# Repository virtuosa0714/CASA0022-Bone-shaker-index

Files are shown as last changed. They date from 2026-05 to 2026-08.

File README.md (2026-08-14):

# The Bone-Shaker Index 🚲💥

> **Mapping Road Surface Integrity & Comfort-Optimised Routing for Urban Micro-Mobility**
> 
> *A Master's Dissertation Project for MSc Connected Environments at UCL CASA.*






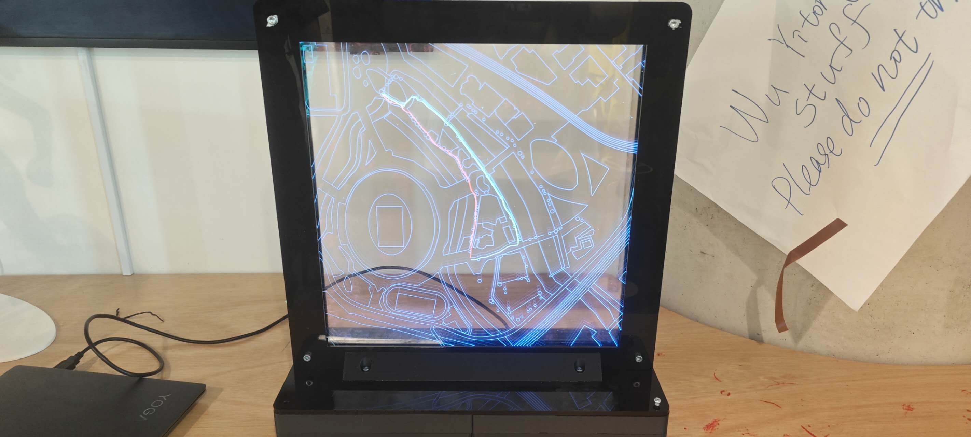
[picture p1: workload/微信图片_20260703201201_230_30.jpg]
Project Banner


## 📖 Overview

The promotion of active travel relies heavily on the quality and safety of cycling infrastructure. Traditional road surface monitoring methods are vehicle-centric, expensive, and fail to capture the high-frequency vibrations experienced by micro-mobility users. 

**The Bone-Shaker Index** is an open-source, low-cost Internet of Things (IoT) participatory sensing framework. It utilizes a bicycle-mounted edge-computing node to continuously monitor pavement conditions. By categorizing road anomalies and pushing this geospatial data to the cloud, the system empowers cyclists with a **Comfort-Weighted Pathfinding Algorithm** that prioritizes structural safety and ride smoothness over the shortest geographical distance.

## ✨ Key Features

*   **Edge-Processed Anomaly Detection:** Utilizes an ESP32-S3 and QMI8658 IMU to filter rider-induced kinematics (pedaling/steering) and accurately categorize infrastructural degradation (Moderate vs. Severe bumps) locally using a 1500ms debounce filter.
*   **Mobile Gateway Sync:** A Flutter-based mobile application that pairs with the hardware via BLE, appends precise GPS telemetry, and asynchronously syncs payloads to a NoSQL Firebase backend.
*   **Comfort-Weighted Dijkstra Routing:** A custom Leaflet.js web dashboard that mathematically penalizes degraded road nodes, actively routing cyclists around hazardous infrastructure.
*   **Tangible Data Visualisation:** A bespoke 3-tier, laser-cut physical exhibition model internally illuminated by LEDs, translating abstract JSON routing arrays into a compelling boundary object for urban advocacy.

---

## 🏗️ System Architecture

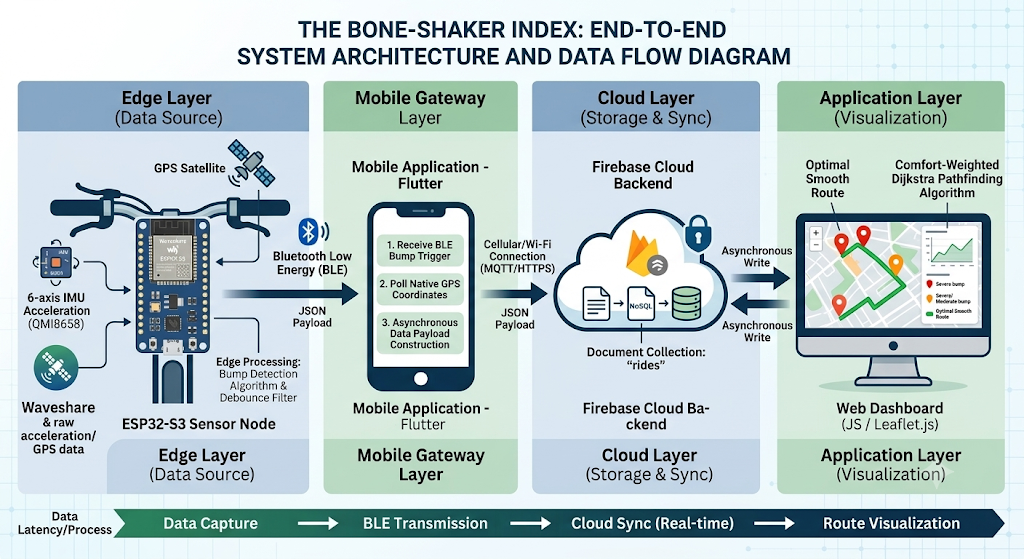
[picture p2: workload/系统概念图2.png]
System Architecture


The architecture operates sequentially across three primary nodes:
1.  **Edge Layer:** ESP32-S3 IMU sampling, gravity filtering, and BLE transmission.
2.  **Mobile Gateway:** Flutter app for GPS tagging and cellular cloud uplink.
3.  **Cloud & App Layer:** Firestore database synchronization and Leaflet.js rendering.

---

## 🛠️ Hardware Setup

The physical core is built around the **Waveshare ESP32-S3 Touch AMOLED 1.75**. To ensure the highest fidelity of inertial data, the sensor node is rigidly mounted to the bicycle's central main frame (top tube), effectively isolating steering noise.

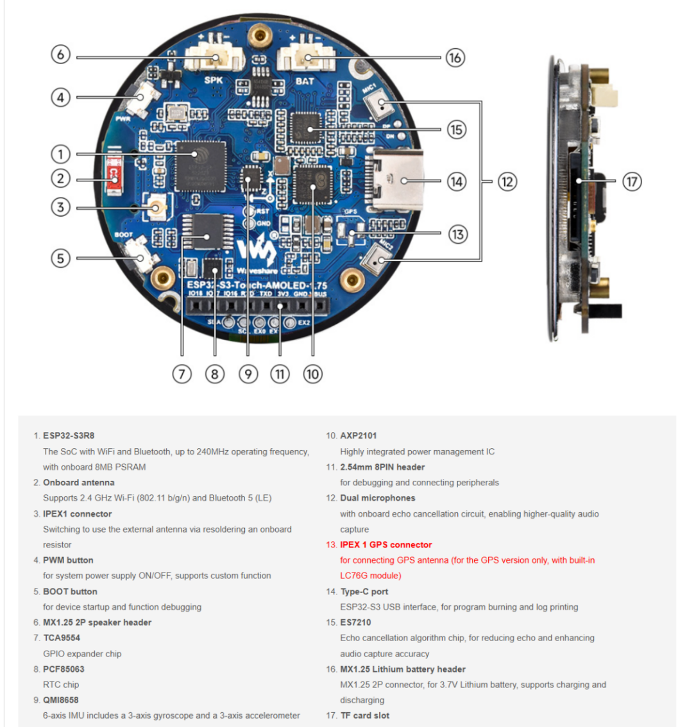
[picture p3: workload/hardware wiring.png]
Hardware Wiring and Mount


**Enclosure Design:**
A custom, weather-resistant enclosure was modeled in Autodesk Fusion and 3D printed. It enforces tight internal tolerances for the ESP32-S3 and Li-Po battery to minimize artificial high-frequency rattling. STL files are available in the `hardware_design/` folder.

---

## 💻 Software & Deployment

### 1. Edge Node Firmware (C++)
*   **Directory:** `/firmware`
*   **Setup:** Built with Arduino IDE / PlatformIO. Ensure the `ESP32` board manager is installed.
*   **Logic:** Samples Z-axis variance. `|ΔZ| >= 0.45G` (Moderate), `|ΔZ| >= 0.65G` (Severe).

### 2. Mobile Gateway (Flutter)
*   **Directory:** `/mobile_app`
*   **Setup:** Run `flutter pub get` to install BLE and Firebase dependencies.
*   **Function:** Background BLE scanning, GPS polling, and real-time UI feedback (Live Sync Active).

### 3. Web Dashboard (JavaScript / Leaflet.js)
*   **Directory:** `/web_dashboard`
*   **Setup:** A static web app. Configure your `firebaseConfig` object in `index.js`.
*   **Algorithm:** Implements coordinate-snapping (11m accuracy) and the custom Comfort-Weighted Dijkstra Algorithm.

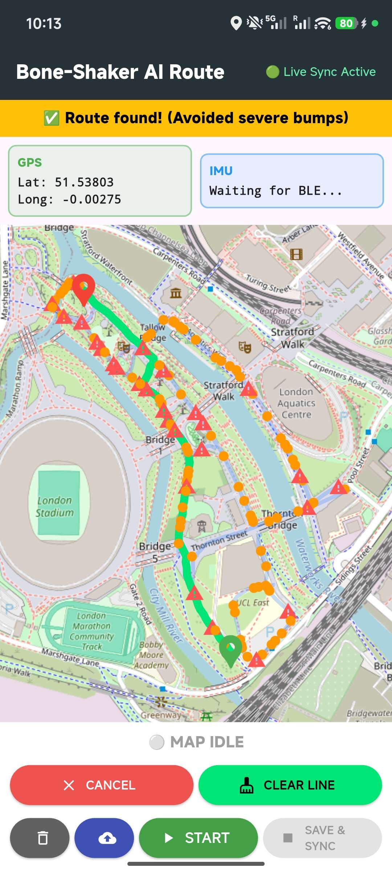
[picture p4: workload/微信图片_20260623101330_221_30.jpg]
App Dashboard
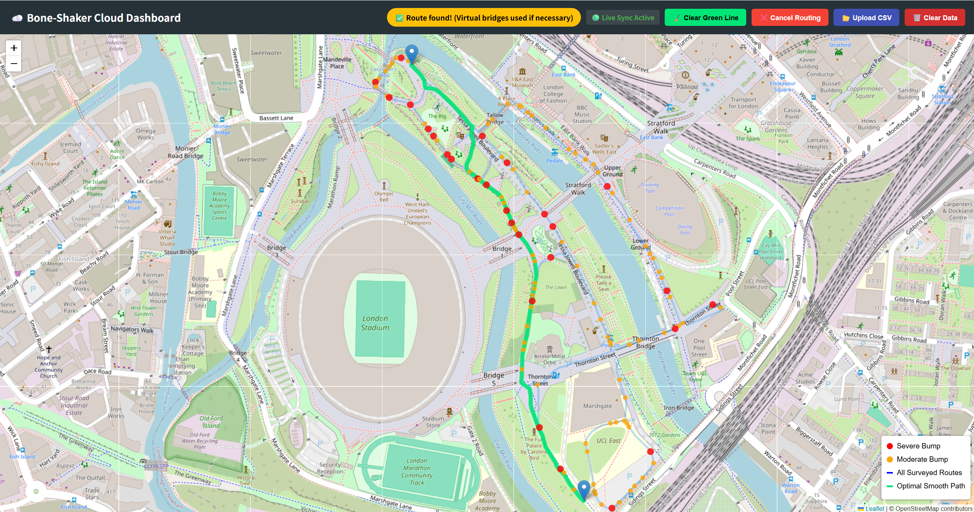
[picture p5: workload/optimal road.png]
Web Dashboard
 

---

## 📂 Repository Structure

```text
CASA0022-Bone-shaker-index/
│
├── firmware/                 # C++ source code for ESP32-S3 edge processing
├── mobile_app/               # Flutter mobile application (BLE Gateway & UI)
├── web_dashboard/            # Leaflet.js interactive map and routing engine
├── hardware_design/          # 3D STL files for enclosure & Laser-cut CAD files
├── data_analysis/            # Python scripts / Jupyter notebooks for CSV evaluation
├── docs/                     # Images, diagrams, and dissertation assets
└── README.md

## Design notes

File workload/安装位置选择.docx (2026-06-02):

通过直接的数据比对，结论非常明确：中间横梁（Main Frame）的效果远远好于前面把手（Handlebar）。

以下是基于你的真实测试数据得出的深度分析：

1. X轴（左右晃动）：把手位置的“转向噪音”极大

把手 (Handlebar) X轴波动标准差：0.216 g

横梁 (Main Frame) X轴波动标准差：0.087 g

分析：你可以从图表的第二栏（X-Axis）明显看到，蓝色线条（把手）的波动幅度远超红色线条（横梁），噪音是横梁的 2.5倍。这是因为在骑行过程中，为了保持平衡或避让，你的双手会不断微调方向盘。把手上的传感器把这些“人为的转向动作”全都记录成了加速度，这会严重干扰我们对“路面坑洼”的判断。横梁则非常稳定。

2. Y轴（前后加减速）：把手的姿态变化更多

把手 (Handlebar) Y轴波动标准差：0.165 g

横梁 (Main Frame) Y轴波动标准差：0.093 g

分析：图表第三栏（Y-Axis）显示，把手的纵向数据波动更大。当你捏刹车、身体前倾或摇车踩踏时，把手会发生位移或姿态倾斜。而车架中间横梁作为一个刚性整体，受骑行者姿势改变的干扰较小。

3. Z轴（上下颠簸）：横梁更能反映真实路况

最大瞬时冲击力 (Max Magnitude)：把手 2.19 g vs 横梁 1.96 g

分析：图表第一栏（Z-Axis）代表了我们最关心的上下颠簸（也是判定 The Bone-Shaker Index 的核心数据）。

把手的 Z 轴数据往往“失真”。一方面是因为前叉的形变或前避震器吸收了部分震动，另一方面由于双手压在把手上，人体手臂相当于“人肉避震”，导致短促而真实的地面冲击被放大或平滑掉了。

横梁的 Z 轴数据更加“纯粹”。横梁是自行车的承载骨架，它的 Z 轴加速度能更忠实地反映轮胎压过坑洼时车架受到的物理刚性冲击。

最终建议：选择“中间横梁”

既然装在后轮旁边容易引起干涉，那么装在中间横梁（上管或下管）就是你目前最佳的选择。

横梁位置的测试数据证明了：

它过滤掉了绝大部分由手部动作引起的 X 轴和 Y 轴假信号（噪音极低）。

它作为一个刚性结构，能够清晰、干净地记录下每一次颠簸（Z轴波动清晰）。

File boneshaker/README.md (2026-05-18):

# boneshaker

A new Flutter project.

## Getting Started

This project is a starting point for a Flutter application.

A few resources to get you started if this is your first Flutter project:

- [Learn Flutter](https://docs.flutter.dev/get-started/learn-flutter)
- [Write your first Flutter app](https://docs.flutter.dev/get-started/codelab)
- [Flutter learning resources](https://docs.flutter.dev/reference/learning-resources)

For help getting started with Flutter development, view the
[online documentation](https://docs.flutter.dev/), which offers tutorials,
samples, guidance on mobile development, and a full API reference.

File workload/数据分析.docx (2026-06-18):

数据核心特征提取

通过分析你的 Z 轴（垂直方向）数据，我们得出了以下基准指标：

静止基准线（重力加速度）：平均值为 -0.978 g。这意味着你的传感器 Z 轴是垂直向下的，平时受到的标准重力约为 1g。

常规骑行底噪：标准差（Std Dev）为 0.105 g。这是你平时骑行在普通路面上的轻微震动幅度。

最大颠簸冲击：记录到的最大绝对偏差达到了 0.932 g（瞬间读数接近 -1.91 g）。

判定标准设置建议

为了精准找出“坑洼”，你不能直接用原始的 Acc_Z 读数，而是应该先计算“动态垂直加速度（Dynamic Z）”，即剔除掉地球重力。

计算公式：动态 Z = 绝对值(Acc_Z - (-0.978))

(简算法：取 Acc_Z 绝对值后减去 0.98 即可)

基于你的实测数据（运用统计学的百分位数分布），我为你推荐以下 三级颠簸判定标准：

1. 正常粗糙路面（底噪过滤区）

阈值设置：动态 Z < 0.30 g

数据支撑：在你的测试中，95% 的时间里动态 Z 都小于 0.3g。这意味着只要冲击力低于这个值，都属于正常的柏油路颗粒震动或车架的正常轻微摇晃。程序可以直接忽略不记。

2. 中度颠簸（小坑洼/砖块路/井盖）

阈值设置：0.30 g ≤ 动态 Z < 0.45 g

数据支撑：覆盖了你数据中 95% ~ 99% 的少数波峰。

应用场景：这代表路面有明显的不平整（比如压过下沉的井盖或小裂缝）。如果你要在地图上画出“路况较差”的黄色轨迹，就筛选这个区间。

3. 严重坑洼 / 减速带 (Bone-Shaker 核心数据)

阈值设置：动态 Z ≥ 0.45 g

数据支撑：代表了你整趟骑行中最剧烈的前 1% 的物理冲击。你的最大冲击力达到了 0.93g。

应用场景：这是真正的“骨头粉碎者（Bone-Shaker）”。在地图上，这些点应该被标记为高危红色点位。当你的 App 检测到这个级别的数据时，就可以触发“坑洼记录”。

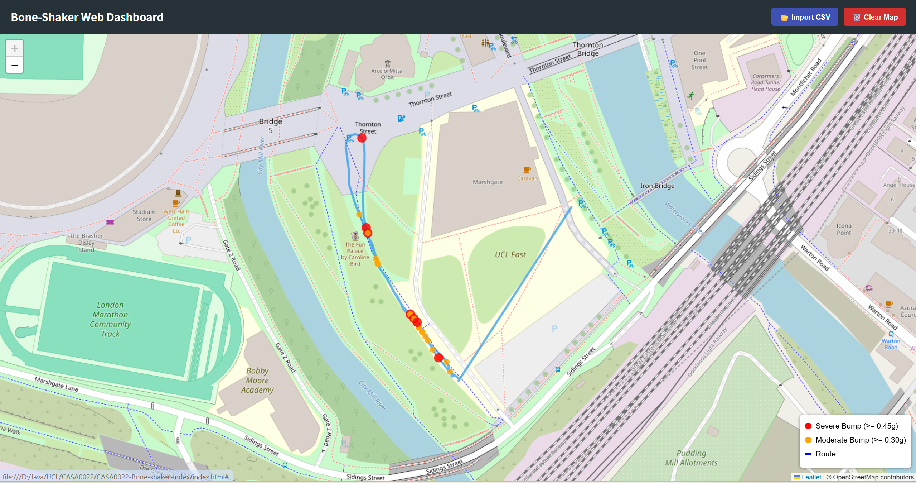
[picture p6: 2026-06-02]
workload/webmap.png

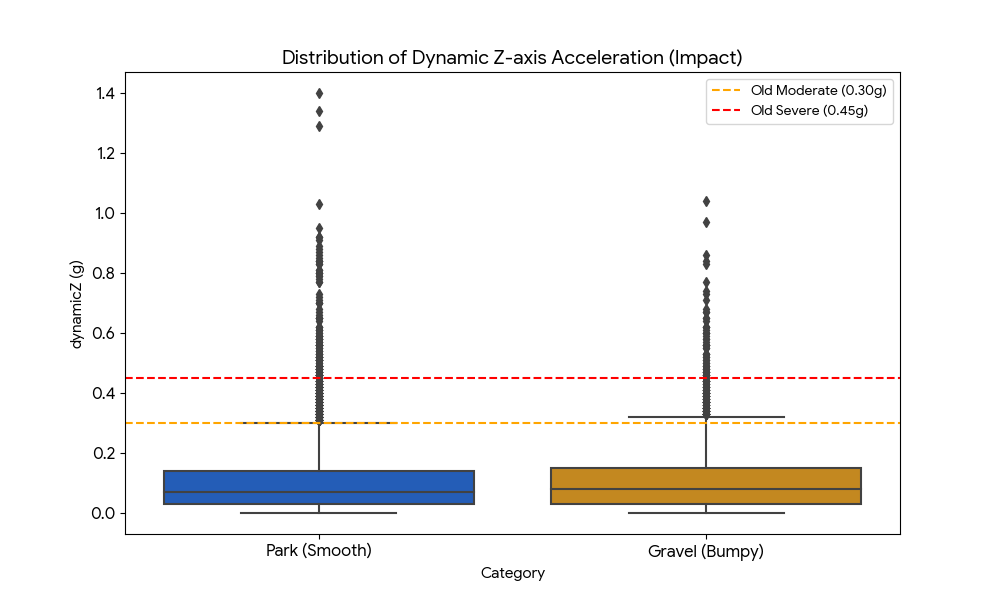
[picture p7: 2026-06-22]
workload/distribution.png

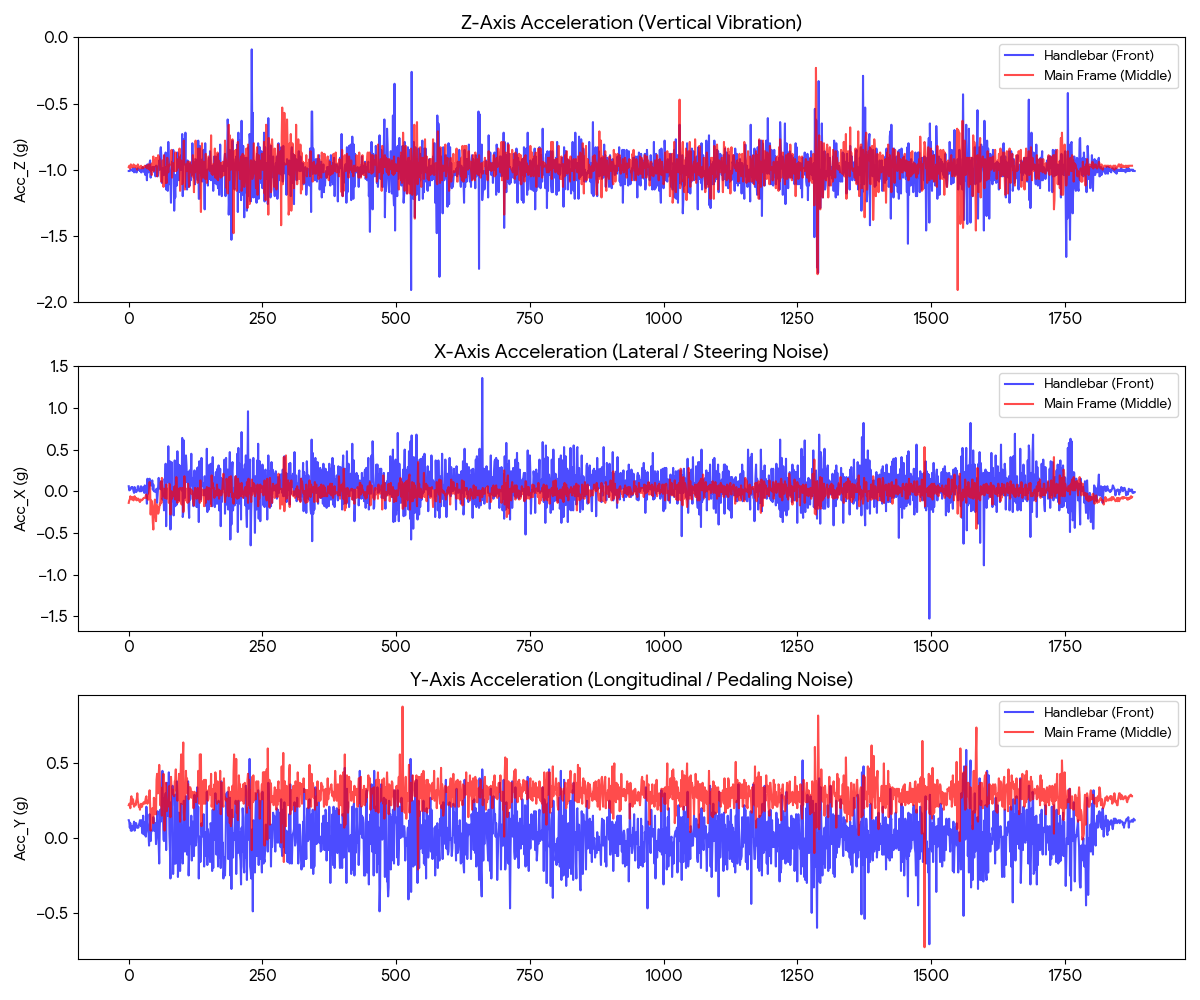
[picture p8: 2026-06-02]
workload/安装位置选择.png

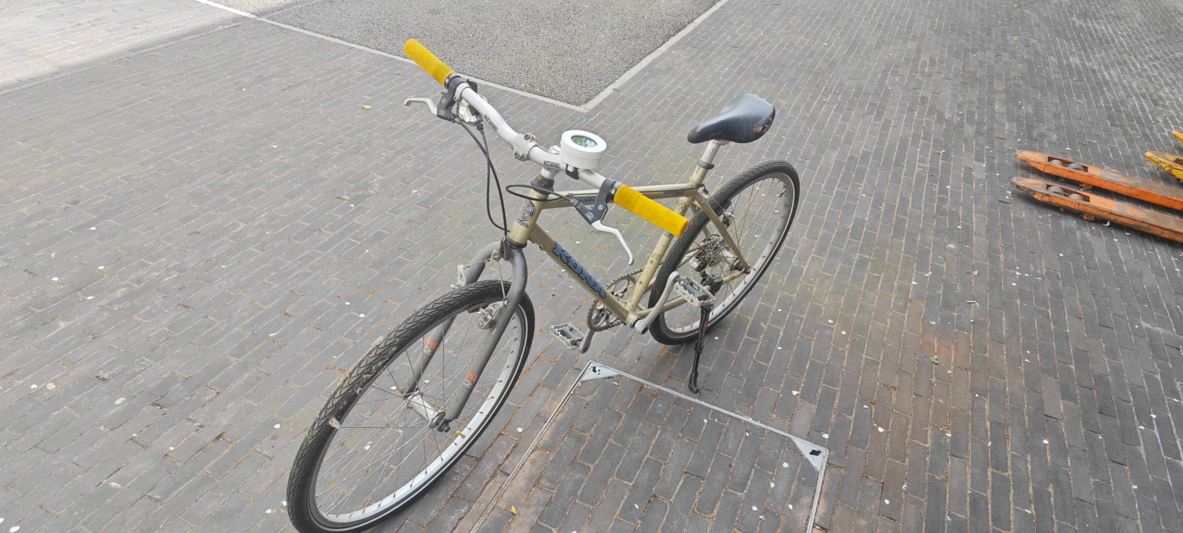
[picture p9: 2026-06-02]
workload/微信图片_20260601122134_171_30.jpg

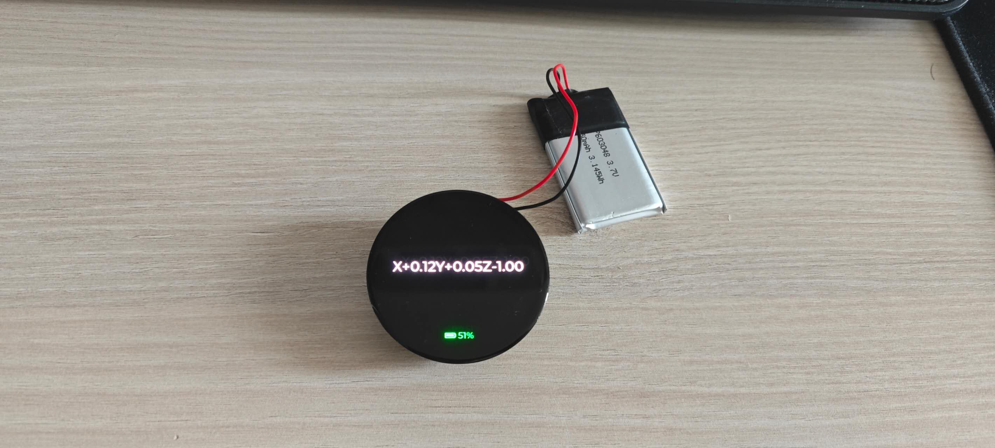
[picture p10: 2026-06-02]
workload/微信图片_20260518105642_153_30.jpg

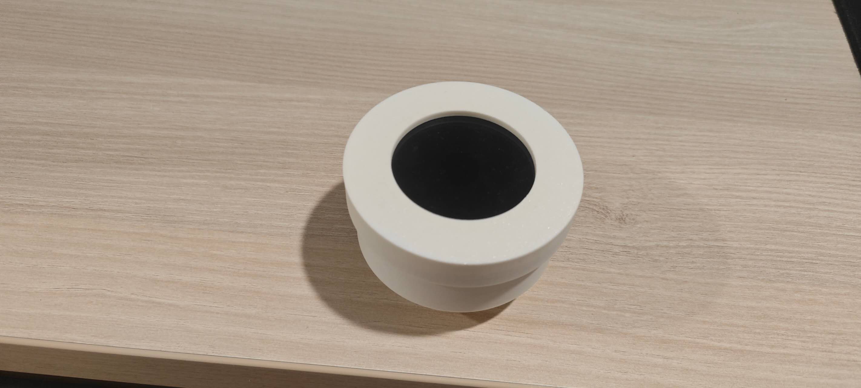
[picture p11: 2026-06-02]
workload/微信图片_20260530215353_166_30.jpg

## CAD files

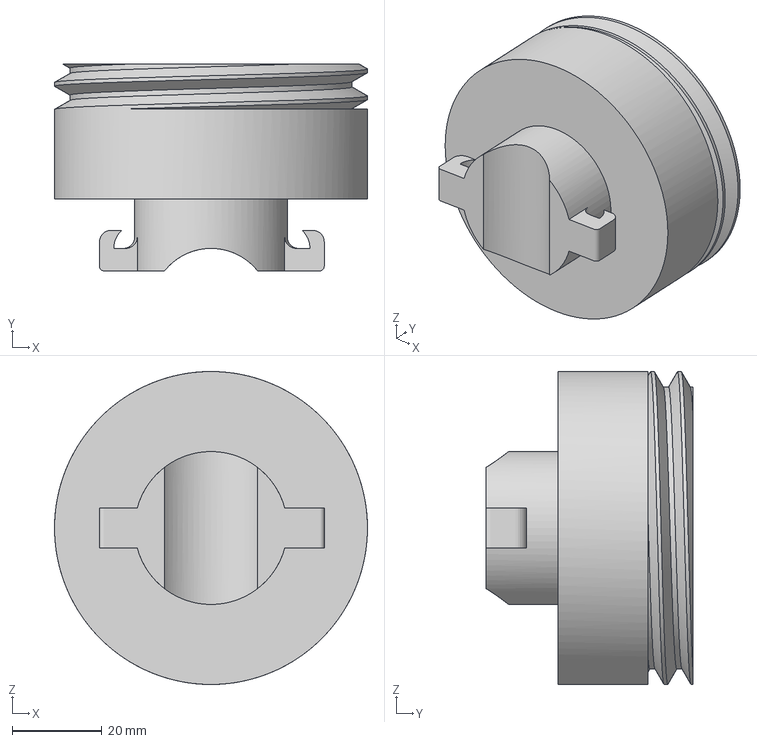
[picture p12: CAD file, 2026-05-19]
3Dprint/Body8.3mf
69.6 x 46.0 x 69.6 mm

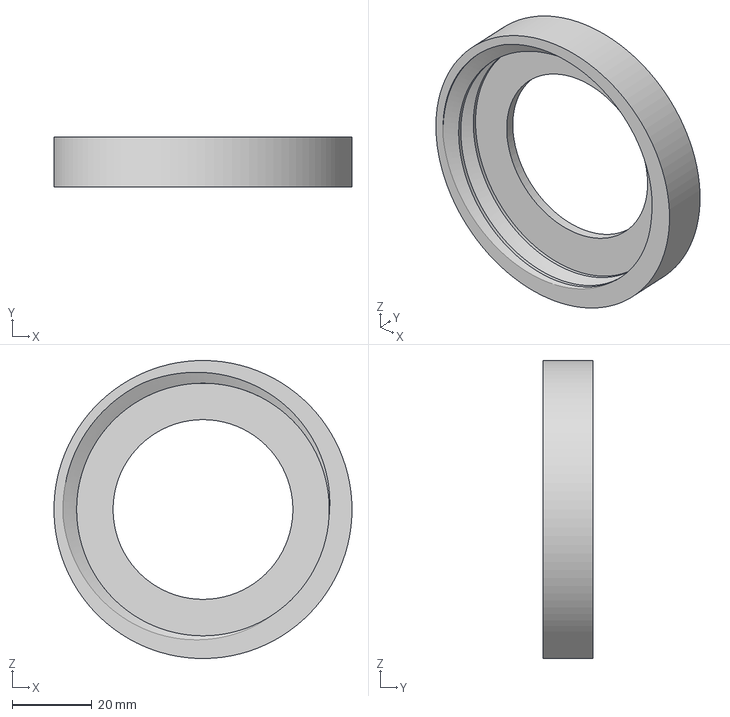
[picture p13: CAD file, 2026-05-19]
3Dprint/Body17.3mf
74.6 x 12.5 x 74.6 mm

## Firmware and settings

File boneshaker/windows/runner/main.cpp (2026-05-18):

#include <flutter/dart_project.h>
#include <flutter/flutter_view_controller.h>
#include <windows.h>

#include "flutter_window.h"
#include "utils.h"

int APIENTRY wWinMain(_In_ HINSTANCE instance, _In_opt_ HINSTANCE prev,
                      _In_ wchar_t *command_line, _In_ int show_command) {
  // Attach to console when present (e.g., 'flutter run') or create a
  // new console when running with a debugger.
  if (!::AttachConsole(ATTACH_PARENT_PROCESS) && ::IsDebuggerPresent()) {
    CreateAndAttachConsole();
  }

  // Initialize COM, so that it is available for use in the library and/or
  // plugins.
  ::CoInitializeEx(nullptr, COINIT_APARTMENTTHREADED);

  flutter::DartProject project(L"data");

  std::vector<std::string> command_line_arguments =
      GetCommandLineArguments();

  project.set_dart_entrypoint_arguments(std::move(command_line_arguments));

  FlutterWindow window(project);
  Win32Window::Point origin(10, 10);
  Win32Window::Size size(1280, 720);
  if (!window.Create(L"boneshaker", origin, size)) {
    return EXIT_FAILURE;
  }
  window.SetQuitOnClose(true);

  ::MSG msg;
  while (::GetMessage(&msg, nullptr, 0, 0)) {
    ::TranslateMessage(&msg);
    ::DispatchMessage(&msg);
  }

  ::CoUninitialize();
  return EXIT_SUCCESS;
}

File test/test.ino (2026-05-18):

#include <lvgl.h>
#include "Arduino_GFX_Library.h"
#include "pin_config.h"
#include "lv_conf.h"
#include <Arduino.h>
#include <Wire.h>
#include "SensorQMI8658.hpp"

// --- 电源管理库 ---
#include "XPowersLib.h" 

// --- 蓝牙相关头文件 ---
#include <BLEDevice.h>
#include <BLEServer.h>
#include <BLEUtils.h>
#include <BLE2902.h>

#define EXAMPLE_LVGL_TICK_PERIOD_MS 2

// --- 蓝牙配置 UUID ---
#define SERVICE_UUID           "6E400001-B5A3-F393-E0A9-E50E24DCCA9E"
#define CHARACTERISTIC_UUID_TX "6E400003-B5A3-F393-E0A9-E50E24DCCA9E"

BLEServer *pServer = NULL;
BLECharacteristic *pTxCharacteristic;
bool deviceConnected = false;

// 蓝牙连接状态回调
class MyServerCallbacks: public BLEServerCallbacks {
    void onConnect(BLEServer* pServer) {
      deviceConnected = true;
    };
    void onDisconnect(BLEServer* pServer) {
      deviceConnected = false;
      pServer->getAdvertising()->start();
    }
};

static lv_disp_draw_buf_t draw_buf;
static lv_color_t buf[LCD_WIDTH * LCD_HEIGHT / 10];
SensorQMI8658 qmi;
IMUdata acc;

// --- 电源管理与电量显示对象 ---
XPowersPMU power;
lv_obj_t *label_battery; 
lv_obj_t *label;

Arduino_DataBus *bus = new Arduino_ESP32QSPI(
  LCD_CS, LCD_SCLK, LCD_SDIO0, LCD_SDIO1, LCD_SDIO2, LCD_SDIO3);
Arduino_CO5300 *gfx = new Arduino_CO5300(
  bus, LCD_RESET, 0, LCD_WIDTH, LCD_HEIGHT, 6, 0, 0, 0);

void my_disp_flush(lv_disp_drv_t *disp, const lv_area_t *area, lv_color_t *color_p) {
  uint32_t w = (area->x2 - area->x1 + 1);
  uint32_t h = (area->y2 - area->y1 + 1);
#if (LV_COLOR_16_SWAP != 0)
  gfx->draw16bitBeRGBBitmap(area->x1, area->y1, (uint16_t *)&color_p->full, w, h);
#else
  gfx->draw16bitRGBBitmap(area->x1, area->y1, (uint16_t *)&color_p->full, w, h);
#endif
  lv_disp_flush_ready(disp);
}

void example_increase_lvgl_tick(void *arg) {
  lv_tick_inc(EXAMPLE_LVGL_TICK_PERIOD_MS);
}

void setup() {
  Serial.begin(115200);
  Wire.begin(IIC_SDA, IIC_SCL);

  // --- 电源管理芯片初始化 ---
  if(power.begin(Wire, AXP2101_SLAVE_ADDRESS, IIC_SDA, IIC_SCL)) {
    power.clearIrqStatus();
    power.enableBattVoltageMeasure();
    power.enableVbusVoltageMeasure(); 
  } else {
    Serial.println("PMU Init Failed!");
  }

  gfx->begin();
  gfx->setBrightness(200);

  // --- 蓝牙初始化 ---
  BLEDevice::init("ESP32_S3_IMU");
  pServer = BLEDevice::createServer();
  pServer->setCallbacks(new MyServerCallbacks());

  BLEService *pService = pServer->createService(SERVICE_UUID);
  pTxCharacteristic = pService->createCharacteristic(
                        CHARACTERISTIC_UUID_TX,
                        BLECharacteristic::PROPERTY_NOTIFY
                      );
  pTxCharacteristic->addDescriptor(new BLE2902());
  pService->start();
  pServer->getAdvertising()->start();
  Serial.println("BLE Ready!");

  // --- LVGL 初始化 ---
  lv_init();
  lv_disp_draw_buf_init(&draw_buf, buf, NULL, LCD_WIDTH * LCD_HEIGHT / 10);
  static lv_disp_drv_t disp_drv;
  lv_disp_drv_init(&disp_drv);
  disp_drv.hor_res = LCD_WIDTH;
  disp_drv.ver_res = LCD_HEIGHT;
  disp_drv.flush_cb = my_disp_flush;
  disp_drv.draw_buf = &draw_buf;
  lv_disp_drv_register(&disp_drv);

  const esp_timer_create_args_t lvgl_tick_timer_args = {
    .callback = &example_increase_lvgl_tick,
    .name = "lvgl_tick"
  };
  esp_timer_handle_t lvgl_tick_timer = NULL;
  esp_timer_create(&lvgl_tick_timer_args, &lvgl_tick_timer);
  esp_timer_start_periodic(lvgl_tick_timer, EXAMPLE_LVGL_TICK_PERIOD_MS * 1000);

  // ==========================================
  // 修改点：完全照搬 DeviceCode 的 UI 绘制逻辑
  // ==========================================
  // 1. 设置黑色背景
  lv_obj_set_style_bg_color(lv_scr_act(), lv_color_hex(0x000000), LV_PART_MAIN);

  // 2. 电池 UI 标签 (完全沿用你的参考代码样式)
  label_battery = lv_label_create(lv_scr_act());
  lv_obj_set_width(label_battery, 200); 
  lv_obj_set_style_text_color(label_battery, lv_color_hex(0x00FF00), LV_PART_MAIN);
  lv_obj_set_style_text_font(label_battery, &lv_font_montserrat_24, LV_PART_MAIN);
  lv_label_set_text(label_battery, LV_SYMBOL_BATTERY_FULL " --%");
  lv_obj_set_style_text_align(label_battery, LV_TEXT_ALIGN_CENTER, LV_PART_MAIN);
  lv_obj_align(label_battery, LV_ALIGN_BOTTOM_MID, 0, -40);

  // 3. 原有 IMU 数据标签 (改为白色，防止在黑色背景上隐身)
  label = lv_label_create(lv_scr_act());
  lv_obj_set_width(label, disp_drv.hor_res);
  lv_obj_set_style_text_color(label, lv_color_hex(0xFFFFFF), LV_PART_MAIN);
  lv_obj_set_style_text_align(label, LV_TEXT_ALIGN_CENTER, 0);
  lv_obj_set_style_text_font(label, &lv_font_montserrat_40, 0);
  lv_obj_set_style_text_line_space(label, 10, 0);
  lv_obj_align(label, LV_ALIGN_CENTER, 0, -20); // 稍微往上移一点，不要挡住电量
  lv_label_set_text(label, "Initializing...");

  if (!qmi.begin(Wire, QMI8658_L_SLAVE_ADDRESS, IIC_SDA, IIC_SCL)) {
    lv_label_set_text(label, "Sensor Error!");
    while (1) { delay(1000); }
  }

  qmi.configAccelerometer(SensorQMI8658::ACC_RANGE_4G, SensorQMI8658::ACC_ODR_1000Hz, SensorQMI8658::LPF_MODE_0);
  qmi.enableAccelerometer();
}

void loop() {
  lv_timer_handler();

  // 定期刷新电池状态（这里保留了 2 秒读取一次的优化，防止 I2C 堵塞导致你主程序的 IMU 掉帧）
  static unsigned long lastBatteryUpdate = 0;
  if (millis() - lastBatteryUpdate > 2000) {
    lastBatteryUpdate = millis();
    char bat_buf[32];
    const char* pwr_icon = LV_SYMBOL_BATTERY_FULL;
    
    // 以下判断逻辑与 DeviceCode.ino 完全一致
    if (power.isVbusIn()) {
      pwr_icon = power.isCharging() ? LV_SYMBOL_CHARGE : LV_SYMBOL_USB;
    }

    if (power.isBatteryConnect()) {
      snprintf(bat_buf, sizeof(bat_buf), "%s %d%%", pwr_icon, power.getBatteryPercent());
    } else {
      snprintf(bat_buf, sizeof(bat_buf), "%s NO BAT", pwr_icon);
    }
    lv_label_set_text(label_battery, bat_buf);
  }

  // --- 读取 IMU 数据并通过蓝牙发送 ---
  if (qmi.getDataReady()) {
    if (qmi.getAccelerometer(acc.x, acc.y, acc.z)) {
      char buf[64];
      snprintf(buf, sizeof(buf), "X%+.2fY%+.2fZ%+.2f", acc.x, acc.y, acc.z);
      lv_label_set_text(label, buf);
      
      if (deviceConnected) {
          pTxCharacteristic->setValue(buf);
          pTxCharacteristic->notify();
      }
      Serial.println(buf);
    }
  }
  delay(50);
}

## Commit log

2026-05-18 app and test program
    [road_data_1778750882088.csv]
2026-05-19 3D print
    [Body17.3mf, Body8.3mf]
2026-08-14 Create hardware wiring.png
